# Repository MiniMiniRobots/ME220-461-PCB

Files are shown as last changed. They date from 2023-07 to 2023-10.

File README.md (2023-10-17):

# PCB Design for ME220 and ME461 Courses

The repository is created for the PCB circuits used in ME220 and ME461 lectures which are offered in Middle East Technical University in Turkey in Fall 2023 term. The main circuit is firstly made for the MiniMiniRobots project, which this repository is forked from.

The main circuit board is made so that this PCB can be used for controlling both Stepper and/or DC motors. The board also have connectorys required to connect OLED screen, Neopixel LED's etc.

The main board is designed for using 5V as main supply but it has Step-down Voltage Regulator so that it can be powered with higher voltages between 5-35V. The board can also be supplied with batteries, which was a requirement for the MiniMiniRobots project, thus it has BMS socket on it.

PCB designs are created on EasyEDA. The complete schematic and layout files for both Altium Designer and EasyEDA are located on their subsequent folders. You can also find PDF file for the schematics.

If you want to direct order the PCB without making any changes, you can use the Gerber files.

## Components on the PCB

### The Main Circuit
The main circuit requires these components to be soldered on their locations on the PCB in order to be function.

| Type of the Component | Details | Notes  |
|---|---|---|
| Resistors | Depends on the Connected Devices | Read [Usage](/Usage.md) file for finding the required resistances |
| Capacitors | 2 x 16V 10µF  | Needs to be Electrolytic (cylindrical) to fit their locations on the PCB  |
| Voltage Regulator | LM2596 Step-Down  | There is 2 regulator with different dimensions, its dimensions should be 43x21x14 $mm^3$ to fit to PCB  |
| JST XH2.54 Male Connectors | 4 x 2-Pin, 1 x 3-Pin, 2 x 5-Pin  | Male Connectors should be soldered to PCB |
| DC Motor Driver | L293D DIP-16 Driver | Do not forget to solder 2 x 6-Pin female 2.54mm headers first|
| Stepper Motor Driver | ULN2003A DIP-16 Driver | The driver which comes with the  28BYJ-48 Stepper Motor Set can be used on the circuit |
| Push Button | 2-pin Tact Button  | Can be used to reset the Pico without disconnecting the power source |
| Dip Switch | 2 Pin Dip Switch | Both of the should be on to pass the power |
| Female Headers | 3 x 1x20, 6 x 1x6 2.54mm | 1x20 female headers can be broken to obtain 1x6 headers |
| Microcontroller Circuit | Rasppberry Pi Pico W | Raspberry Pi Pico can also be used with this circuit but in ME220 and ME461, Pico W is used |

### The Transfer Circuit
The transfer circuit only requires these components to be soldered on their locations on it in order to be function.

| Type of the Component | Details | Notes  |
|---|---|---|
| Female Header | 2 x 1x20 2.54mm | Advising soldering the headers such that the `Middle East Technical University` text stays on the top such that one can read the name of the pins while using the circuits. |
| LED | 1 x 5mm  | Shows if the transfer circuit is powered or not  |
| Resistor | 1 x 220Ω  | Needed for lowering the current passing on the power LED 

While preparing the circuits for usage, please refer [Usage of the Circuits](/Usage.md).

For more detailed explanation for each component on the circuits, one can refer to [Explanation of the Components](/Explanation.md).

## Designed Board Pictures

### The Main Circuit
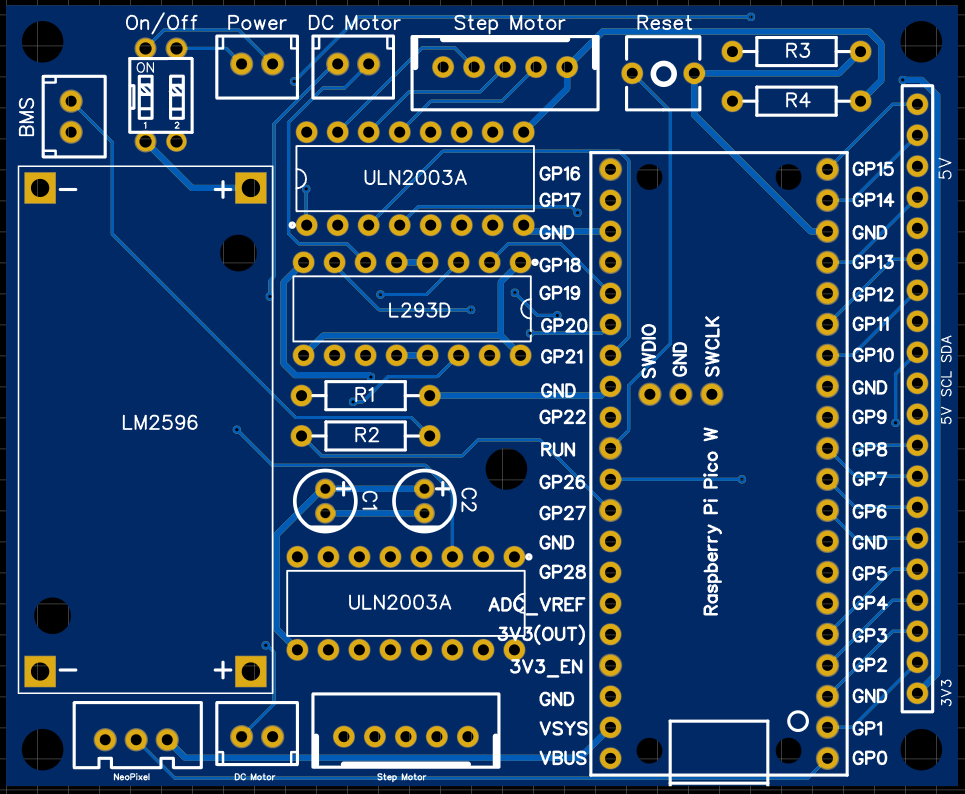
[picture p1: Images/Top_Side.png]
Top of the Main Board Top Side

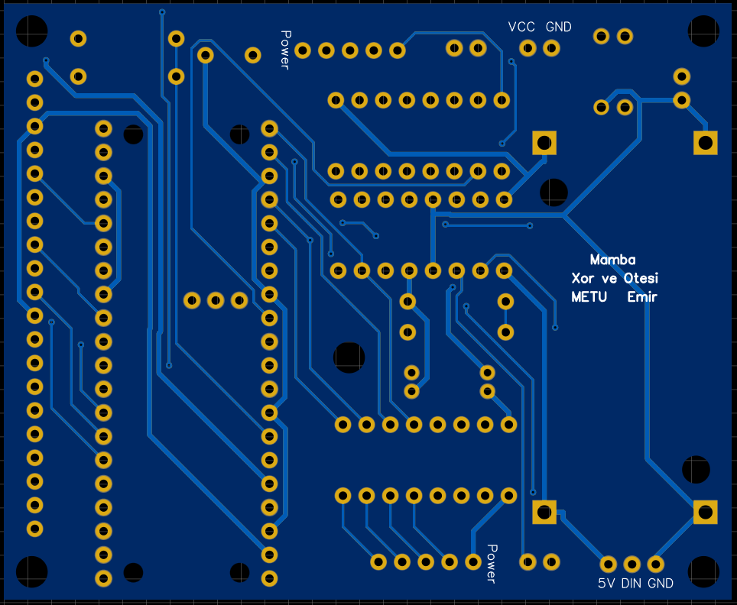
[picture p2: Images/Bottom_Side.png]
Bottom of the Main Board Bottom Side

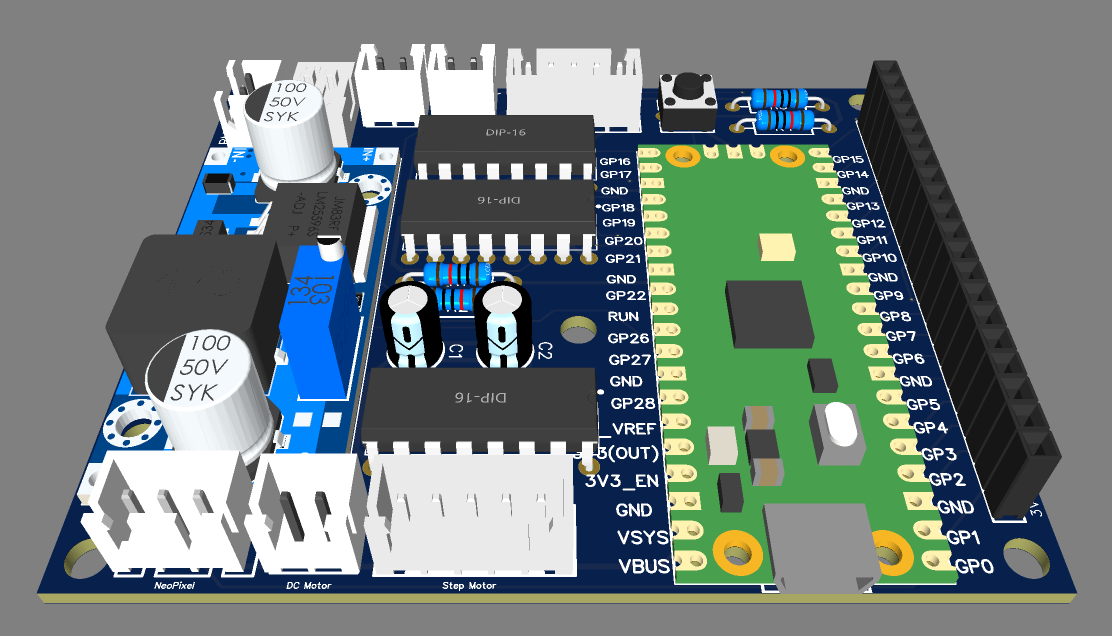
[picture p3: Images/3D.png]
3D View of the Main PCB 3D View


## The Transfer Circuit
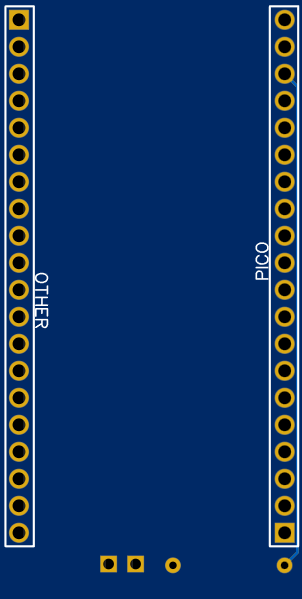
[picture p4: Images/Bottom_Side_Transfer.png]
Bottom of the Transfer Board Bottom Side

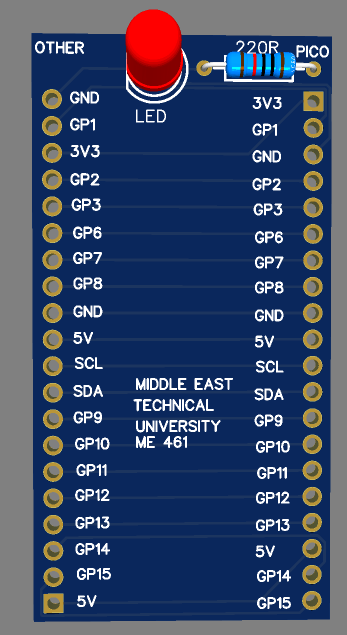
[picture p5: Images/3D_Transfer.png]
3D View of the Transfer PCB 3D View


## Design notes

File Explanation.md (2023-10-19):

# Explanation of the Components on the Circuits

## Main Circuit

| Component Name on PCB | Type of the Component | What It Does  |
|---|---|---|
| BMS | 2 Pin JST XH2.54 Male Connector | Connects BMS device to PCB |
| On-Off | 2 Pin Dip Switch | Manually Controls Main Power |
| Power | 2 Pin JST XH2.54 Male Connector | Connects Main Power Supply to PCB |
| DC Motor | 2 Pin JST XH2.54 Male Connector | Connects a DC Motor to PCB |
| Step Motor | 5 Pin JST XH2.54 Male Connector | Connects a Stepper Motor to PCB|
| Reset | 2 Pin Tact Switch | Resets Pico  |
| R1 | Resistor | Divides BMS Voltage for Battery Level Measurement |
| R2 | Resistor | Divides BMS Voltage for Battery Level Measurement |
| R3 | Resistor | Divides Power Voltage for Power Level Measurement |
| R4 | Resistor | Divides Power Voltage for Power Level Measurement |
| LM2596 | Step-Down Voltage Regulator | Regulates Power to 5V for Pico and other Components which needs 5V |
| ULN2003A | DIP-16 Stepper Motor Driver | Controls 1 stepper motor connected to the circuit with the signals coming from Pico  |
| L293D | DIP-16 DC Motor Driver | Controls 2 DC motor connected to the circuit with the signals coming from Pico |
| C1 | Electrolytic Capacitor | Smoothens Power Input for safer use |
| C2 | Electrolytic Capacitor | Smoothens Power Input for safer use |
| Raspberry Pi Pico W | Microcontroller Board | Microcontroller Board which controls the whole circuit |
| NeoPixel | 3 Pin JST XH2.54 Male Connector | Connects LED Strip to the circuit |

If one wants to use the resistors for voltage reading for BMS or Power level, a voltage divider planning should me made. For more detailed explanation for voltage divider, one can refer [here](https://www.allaboutcircuits.com/tools/voltage-divider-calculator/). The current passing through the resistors should also be considered while finding the required resistance values since the Raspberry Pi Pico cannot handle current values more than 16mA per pin (max 51mA total). Advising that choosing resistors such that the current passing through the resistors are at most 1mA or less. 

For the schematic of the Main Circuit, [Main Circuit Schematic](/Schematic_MiniMiniRobots.pdf)

## Transfer Circuit

| Component Name on PCB | Type of the Component | What It Does  |
|---|---|---|
| PICO | 1x20 2.54mm Male Header  | Connects the Main Circuit to the Transfer Circuit |
| OTHER | 1x20 2.54mm Male Header | Connects the Transfer Circuit to other circuits or a breadboard |
| 220R | 220Ω Resistor  | Decreases the Current for the LED to function |
| LED | 5mm LED  | Shows the Connected Signal |

For the schematic of the Main Circuit, [Transfer Circuit Schematic](/Schematic_ME220-461-PCB.pdf)

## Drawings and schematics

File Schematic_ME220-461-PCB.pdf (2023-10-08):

# SCL 10 VCC 11 GND 12 GP8 13 GP7 14 GP6 15 GP3 16 GP2 17 3V3 18 GP1 19 GND 20

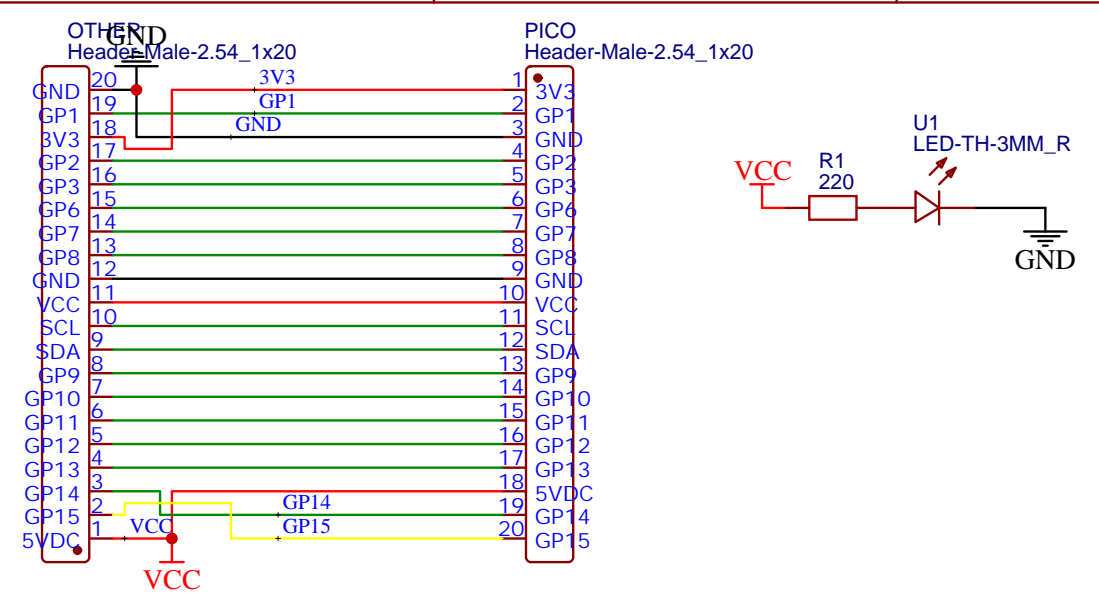
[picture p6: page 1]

Drawn By: Burak Arslan

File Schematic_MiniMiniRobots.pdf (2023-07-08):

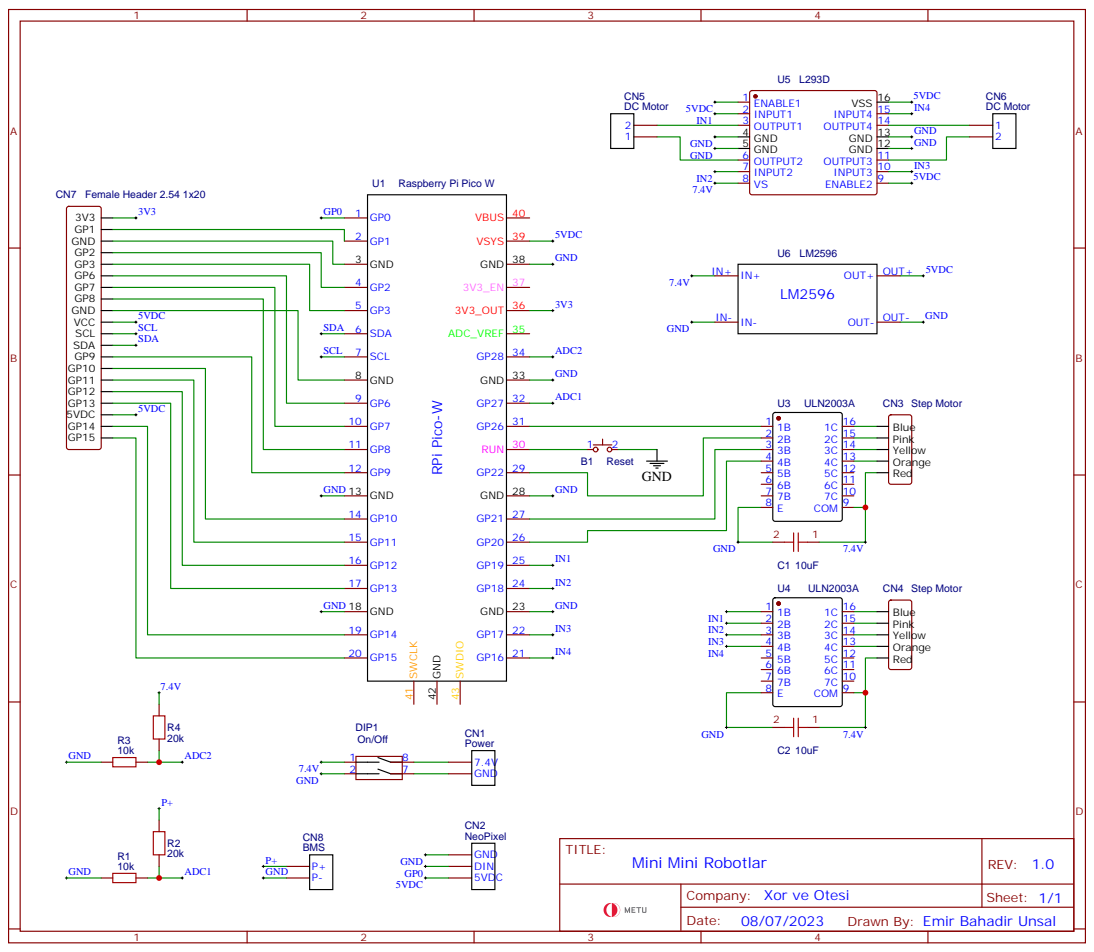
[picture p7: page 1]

Company: Xor ve Otesi

Drawn By: Emir Bahadir Unsal

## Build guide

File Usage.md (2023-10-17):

# Usage of the Circuits

## Usage of The Main Circuit

The Main circuit can operate with Raspberry Pi Pico (or Pico W) and all of the elements except the motors (both DC and Stepper Motors) with USB Power coming from the Pico when connected to a computer or a power adapter. But one needs to be careful while using the circuit with Pico's power input since too much current can be drained from it and the computer USB ports can be damaged (or even the computer motherboard can be damaged). 

For connecting Raspberry Pi Pico and the motor drivers, 2.54mm 6 / 20 pin female headers should be soldered on the circuit first. 

Power port, On/Off Dip Switch and the voltage regulator are needed when the circuit needs to be powered on with an external voltage higher than 5V. Noting that external power source is needed for driving both the DC and stepper motors.

BMS port and R1-R2 resistors are optional and can be used for voltage measurement with Pico when needed. 

R3 and R4 resistors are optional and can be used for voltage measurement coming from Power port.

For driving DC motors, one needs to connect an external power source, L293D motor driver and motors to the circuit.

For driving stepper motors, one needs to connect an external power source, 1 (or 2 for 2 stepper motor driving) ULN2003A stepper motor driver/s and motors to the circuit.

For using strip LEDs, one needs to connect LEDs via NeoPixel port. Here, one needs to be careful about the power need of the LEDs since without an external power source and only power coming from a computers USB port, computer motherboard or the USB port connected can be damaged. 

For connecting the Transfer Circuit, one needs to solder a 1x20 2.54mm female header to the port next to the Pico.

## Usage of The Transfer Circuit

For using the transfer circuit, one needs to solder 2 1x20 2.54mm male headers to their adjacent ports. Advising soldering the headers such that the `Middle East Technical University` text stays on the top such that one can read the name of the pins while using the circuits.

LED and 220R resistor can be soldered for seeing the power connection to the transfer circuit. 

Noting that due to the small design error of the transfer circuit, the transfer circuit is connected with 180degrees rotated to the main circuit.

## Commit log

2023-07-08 8 July
    [Back Body - Charging.step, Back Body.step, Breadboard Holder.step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]
2023-07-08 Added README.md for PCB folder
2023-07-08 Updated README.md
    Fixed Assembly Image on README.md
2023-07-09 Initial Commit for Software
    [my_robot.urdf]
2023-10-06 Created PCB from the forked Repository
    [Back Body - Charging.step, Back Body.step, Breadboard Holder.step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]
2023-10-08 Finalized First Version for Use
    [PCB.pcbdoc, PCB_ME461_2023-10-08.pcbdoc, Sheet.schdoc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]
